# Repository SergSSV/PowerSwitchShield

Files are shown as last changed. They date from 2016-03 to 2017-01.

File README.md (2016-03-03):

Power Switch Shield with S202S02
================================

Simple shield with [2N7002](http://www.nxp.com/documents/data_sheet/2N7002.pdf) MOSFET to drive the [S202S02](http://www.sharpsma.com/webfm_send/303) Solid State Relay.  
The board is panelized to have two sub-boards with one S202S02 and also
a sub-board with three S202S02.

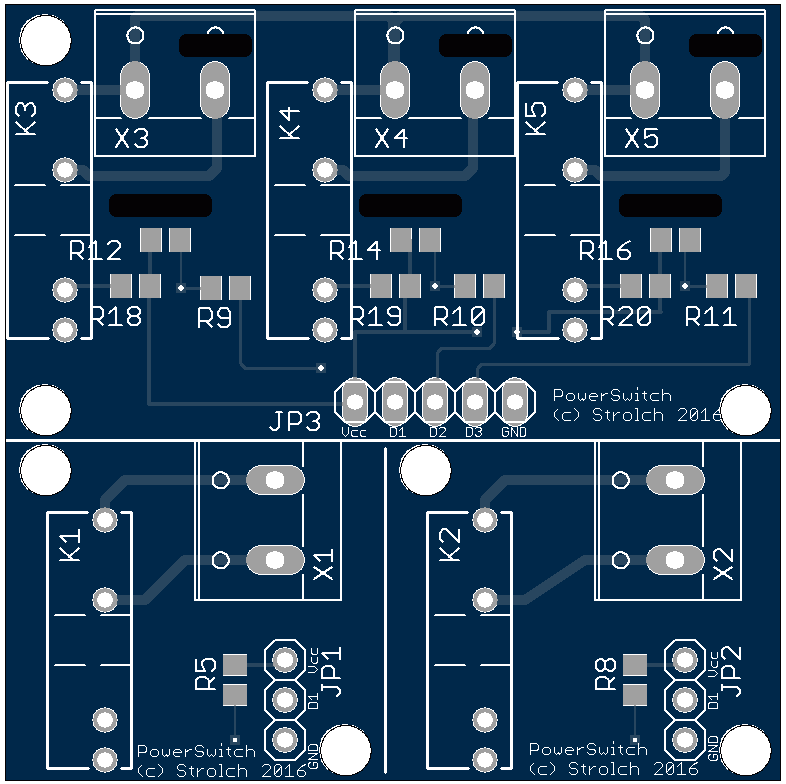
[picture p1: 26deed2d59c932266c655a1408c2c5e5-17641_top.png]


Boards are available from [dirtypcbs.com.](http://dirtypcbs.com/view.php?share=17641&accesskey=2531b32f0bd15d34d1d7f6f8c30357b9)

The PCB contains spare places to solder pull-up / pull-down resistors.  
Pull-Up: R5, R8, R12, R14, R16  
Pull-Down: R6, R7, R13, R15, R17

Resistors (R1, R3, R18, R19, R20) are calculated to get 20mA current at 3.3V supply.  
By using larger values (180R) it may also be used as a 5V shield.

#WARNING
**The shield is designed to switch main power.** So you must care about proper isolation.  
Don't use metal nuts or bolds to fix the board - only use plastic ones!  
For **inductive loads** (e.g. motors) either **connect a [snubber](https://www.google.de/?gws_rd=ssl#q=snubber+circuit)** (surge absorption) circuit as close as possible to the AC clamps or use a *S202S11*.



For AC current > 1A you should consider to use a heat sink (see datasheet "Fig.2 RMS ON-state Current vs. 
Ambient Temperature")!

[Sharp Documentation: Use of Solid State Relays (SSRs)](http://www.datasheetarchive.com/dlmain/SFDatasheet-3/sf-00061711.pdf)

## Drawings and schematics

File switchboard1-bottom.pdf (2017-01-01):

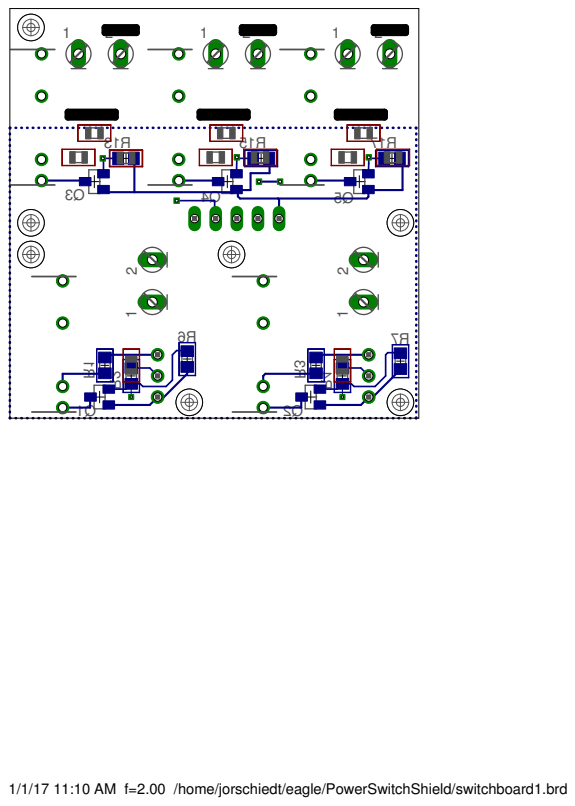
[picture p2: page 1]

1/1/17 11:10 AM f=2.00 /home/jorschiedt/eagle/PowerSwitchShield/switchboard1.brd

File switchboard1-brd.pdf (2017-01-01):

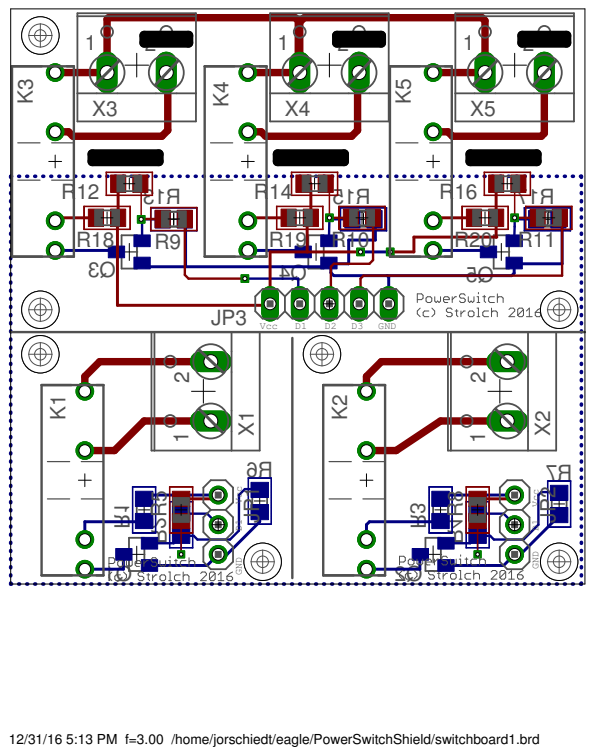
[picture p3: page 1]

12/31/16 5:13 PM f=3.00 /home/jorschiedt/eagle/PowerSwitchShield/switchboard1.brd

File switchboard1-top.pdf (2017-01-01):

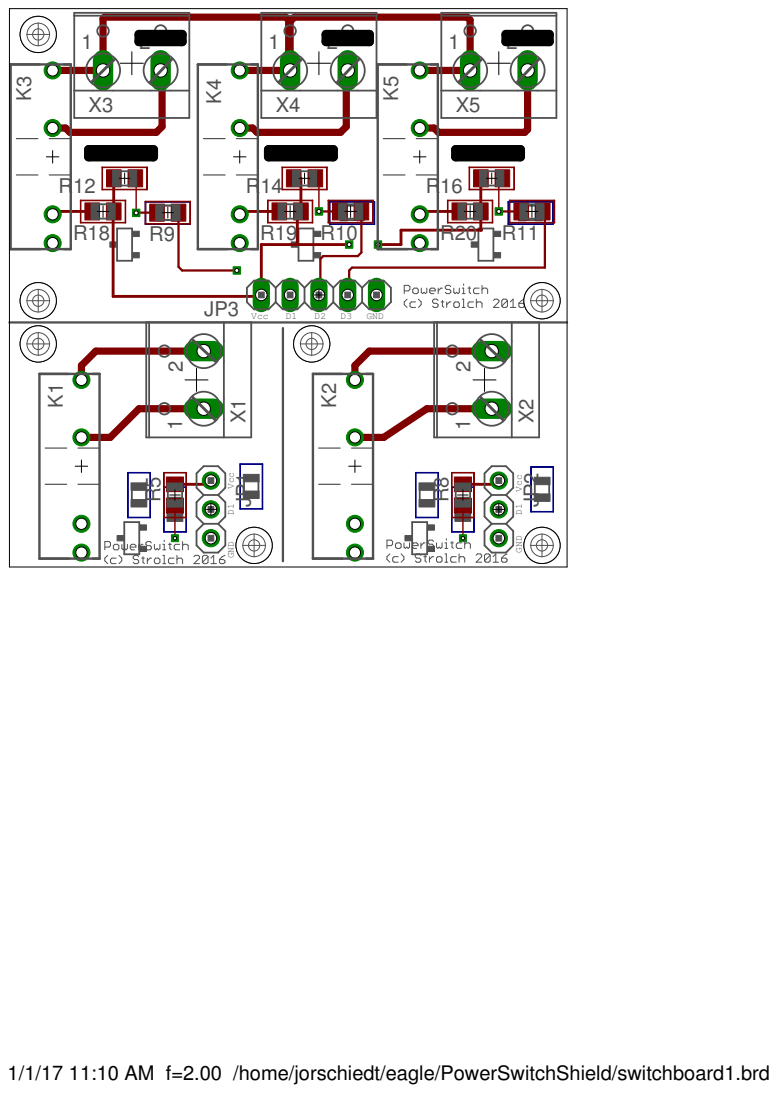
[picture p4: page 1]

1/1/17 11:10 AM f=2.00 /home/jorschiedt/eagle/PowerSwitchShield/switchboard1.brd

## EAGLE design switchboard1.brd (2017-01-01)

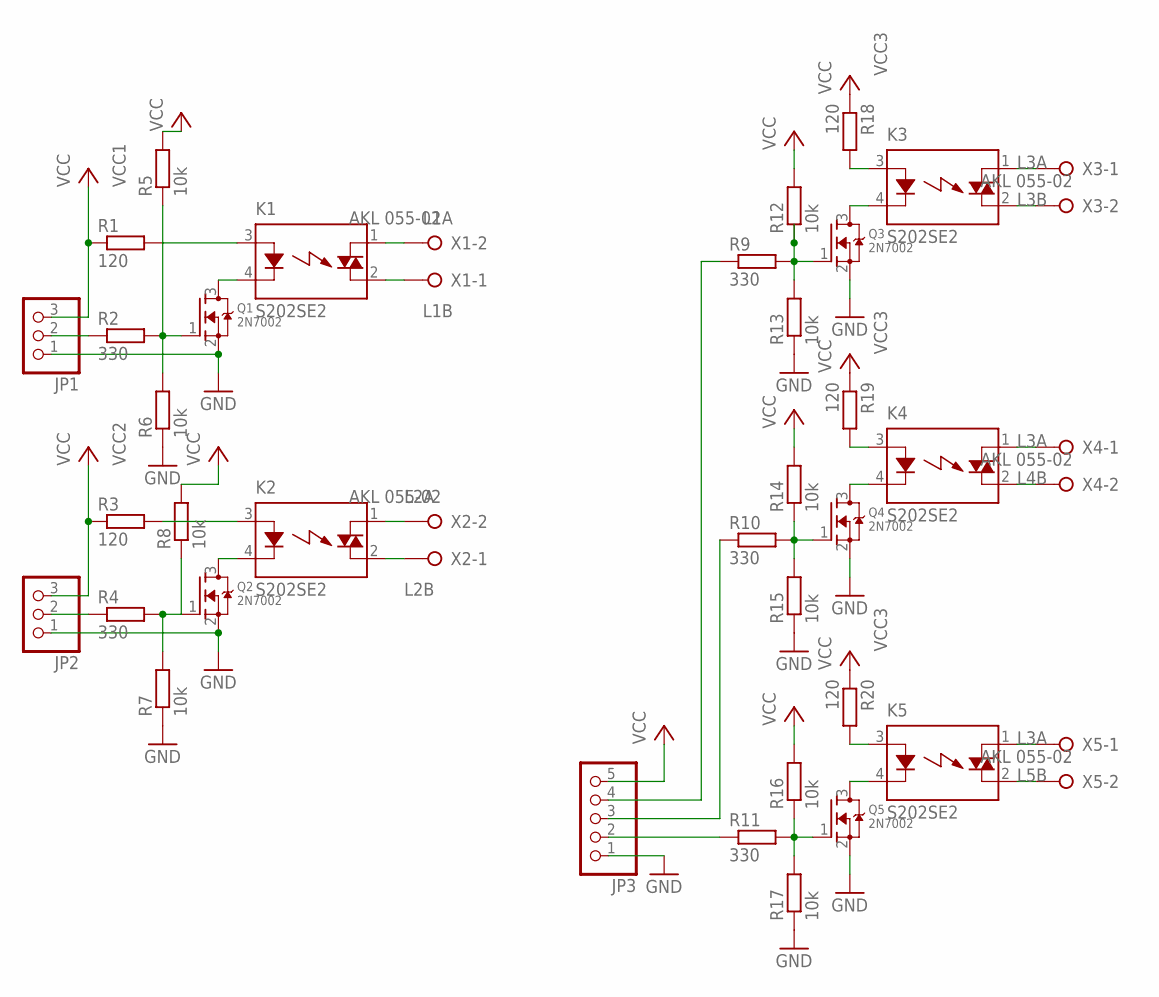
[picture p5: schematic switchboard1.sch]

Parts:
JP1, JP2: PINHD-1X3; 1X03
JP3: PINHD-1X5; 1X05
K1, K2, K3, K4, K5: S202SE2; S2XXEX
Q1, Q2, Q3, Q4, Q5: 2N7002; SOT23
R1, R3, R18, R19, R20: 120; R0805
R2, R4, R9, R10, R11: 330; R0805
R5, R6, R7, R8, R12, R13, R14, R15, R16, R17: 10k; R0805
X1, X2, X3, X4, X5: AKL 055-02; W237-132

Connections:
GND: JP1.1, JP2.1, JP3.1, Q1.2 (S), Q2.2 (S), Q3.2 (S), Q4.2 (S), Q5.2 (S), R6.1, R7.1, R13.1, R15.1, R17.1
L1A: K1.1 (DS1), X1.2
L1B: K1.2 (DS2), X1.1
L2A: K2.1 (DS1), X2.2
L2B: K2.2 (DS2), X2.1
L3A: K3.1 (DS1), K4.1 (DS1), K5.1 (DS1), X3.1, X4.1, X5.1
L3B: K3.2 (DS2), X3.2
L4B: K4.2 (DS2), X4.2
L5B: K5.2 (DS2), X5.2
unnamed: K1.4 (K), Q1.3 (D)
unnamed: K1.3 (A), R1.2
unnamed: Q1.1 (G), R2.2, R5.1, R6.2
unnamed: JP1.2, R2.1
unnamed: K2.3 (A), R3.2
unnamed: K2.4 (K), Q2.3 (D)
unnamed: Q2.1 (G), R4.2, R7.2, R8.1
unnamed: JP2.2, R4.1
unnamed: K3.3 (A), R18.2
unnamed: K3.4 (K), Q3.3 (D)
unnamed: Q3.1 (G), R9.2, R12.1, R13.2
unnamed: JP3.2, R11.1
unnamed: K4.3 (A), R19.2
unnamed: K4.4 (K), Q4.3 (D)
unnamed: Q4.1 (G), R10.2, R14.1, R15.2
unnamed: JP3.3, R10.1
unnamed: K5.3 (A), R20.2
unnamed: K5.4 (K), Q5.3 (D)
unnamed: Q5.1 (G), R11.2, R16.1, R17.2
unnamed: JP3.4, R9.1
VCC1: JP1.3, R1.1, R5.2
VCC2: JP2.3, R3.1, R8.2
VCC3: JP3.5, R12.2, R14.2, R16.2, R18.1, R19.1, R20.1

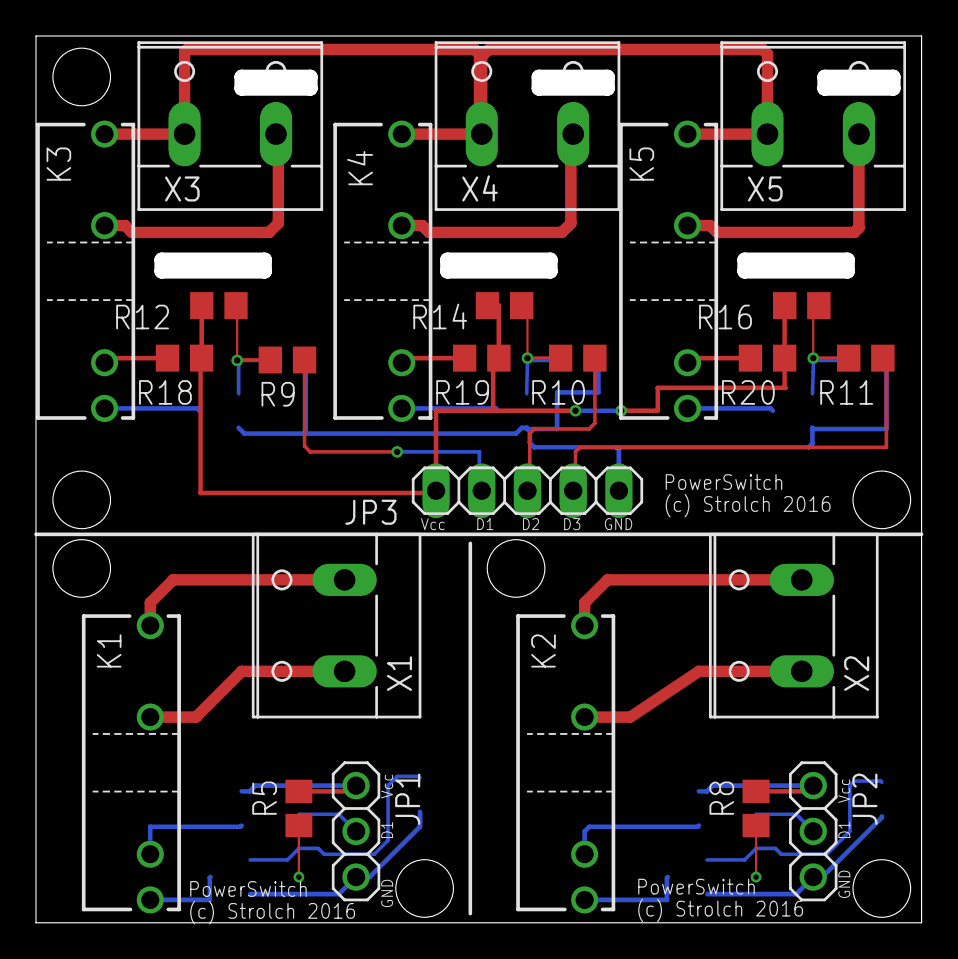
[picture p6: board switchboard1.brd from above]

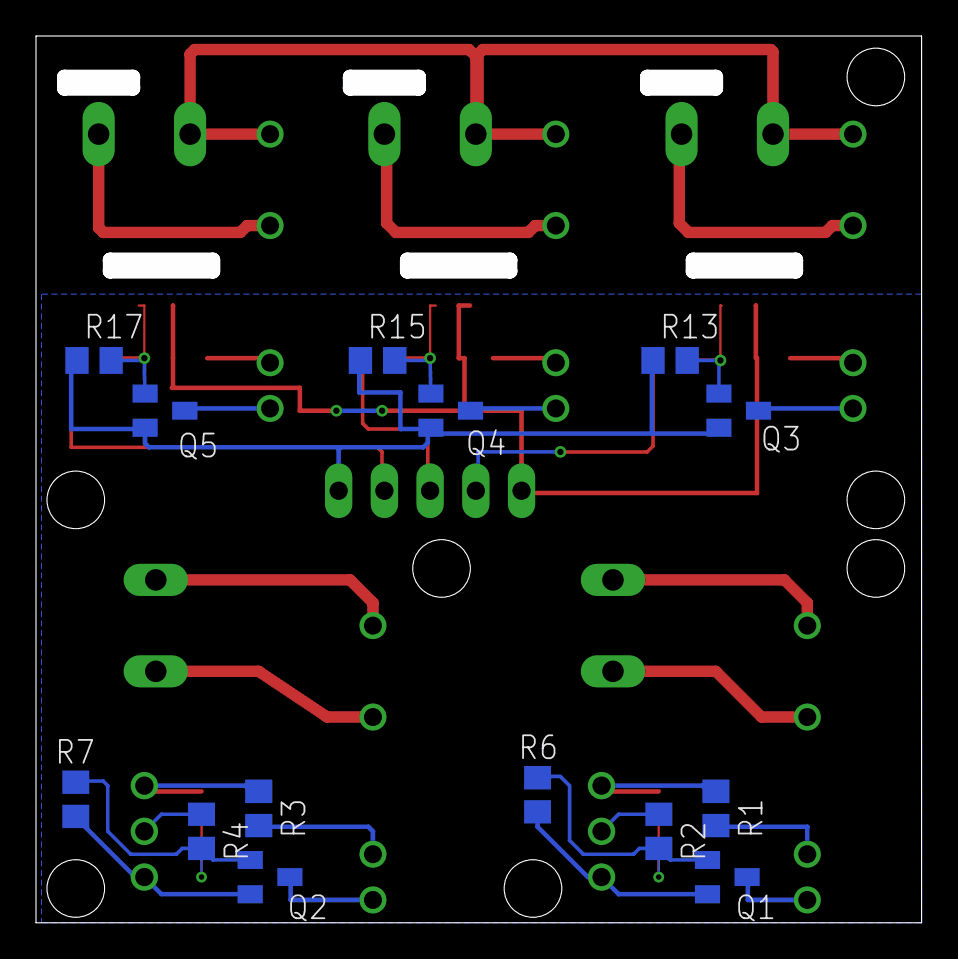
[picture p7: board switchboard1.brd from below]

Board: 2 copper layers, 49.2 x 49.3 mm, 38 parts (14 on the bottom side), 32 nets.

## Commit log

2016-03-03 Power Switch Shield with S202E02 SSR
    [switchboard1.brd, switchboard1.sch]
2016-03-03 eye-candy
    add link to dirtypcbs.com
    add PCB top layer image
2016-03-03 README: add board image
2016-03-03 add snubber circuit schema
2017-01-01 nothing special...
    [switchboard1.brd, switchboard1.sch]
